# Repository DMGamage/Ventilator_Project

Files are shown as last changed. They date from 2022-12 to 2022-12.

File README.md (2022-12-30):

# Ventilator_Project

## The Repository
This repository is where Me and Chamika have developed a Opensource Ventilator Project in Corona Pandamic Situation as a group project on April of 2020. The main purpose of this project is to develop Portable Ventilator that can assist the patient lung pressure . And further more I use this project to develop my ability to work with the arduino and Solidworks and Matlab Designing Skills. I have published our full source code Design files in this repository. 

Ventilator_Project (https://www.youtube.com/watch?v=OVwWnZSBNhI)

### Solidworks Assemble Design1
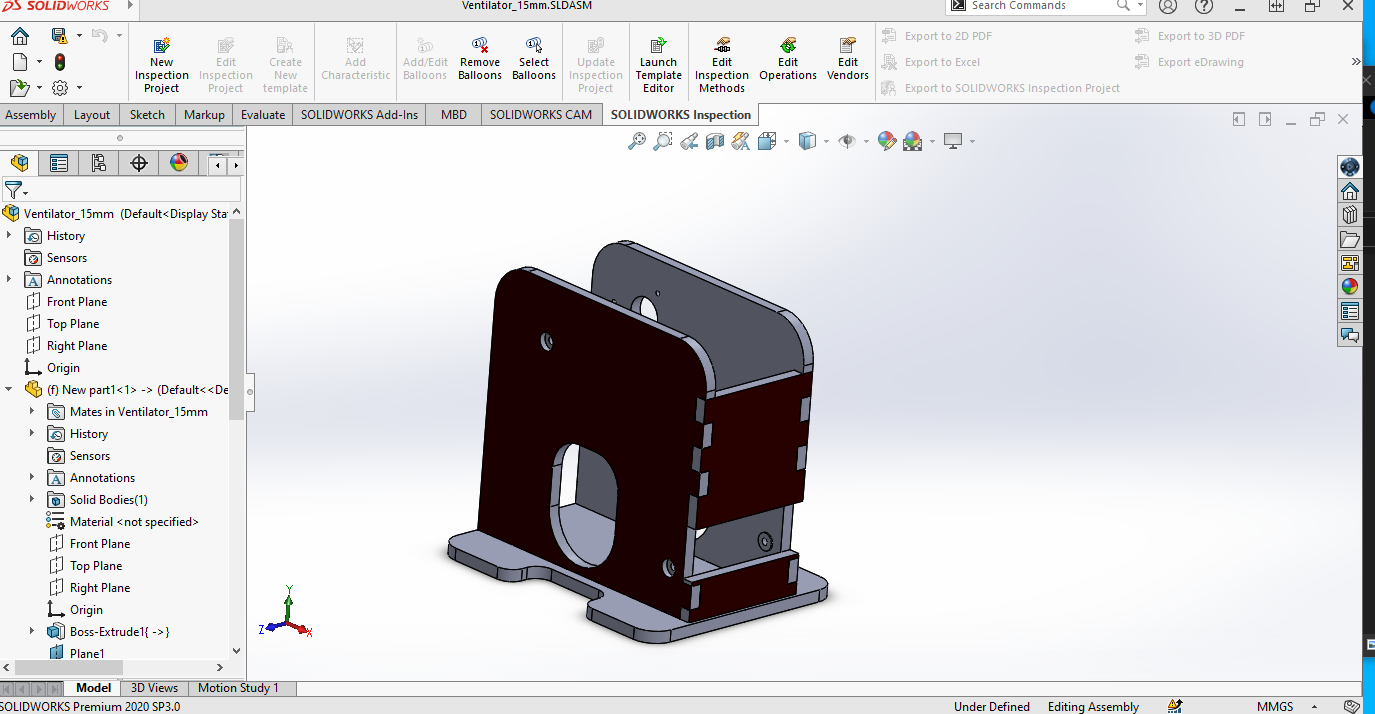
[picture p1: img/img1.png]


### Cam Mechanism Designing Using Matlab
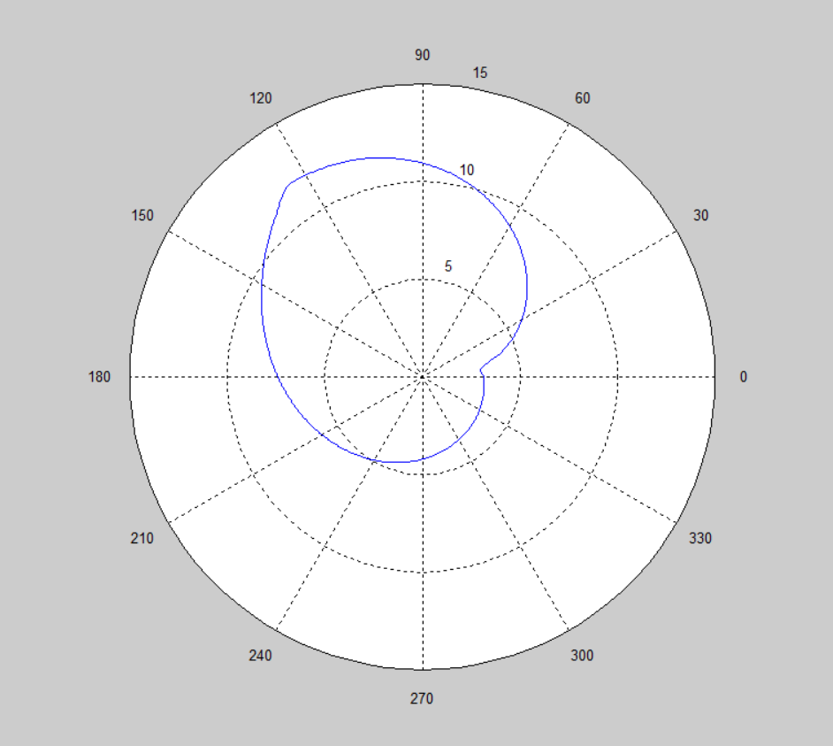
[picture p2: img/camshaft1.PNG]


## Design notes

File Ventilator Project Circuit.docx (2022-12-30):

Ventilator Project Circuit

Parts list

- LCD I2C 16x2 inbuilt display brightness adjustment
- Arduino Nano / Uno
- 30A monster shield board
- 3 push on/off buttons (JST Connectors for setting pushbutton in the casing)
- Encoder input Respiratory rate (Hall sensor to Interrupt or Phase AB encoder)
- Airspeed sensor or BMP 180 sensor
- Piezo buzzer

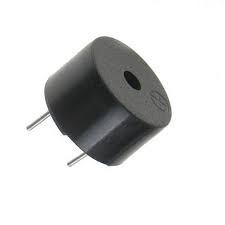
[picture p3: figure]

Basic Machine Connections

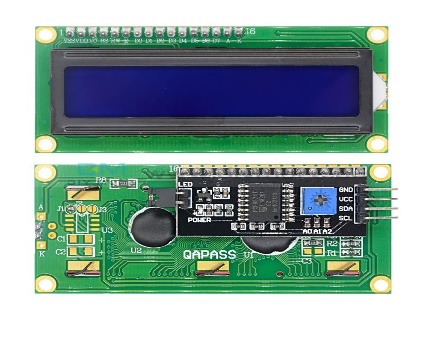
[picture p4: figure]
Using a 16x2 I2C LCD display with ESP32 - Electronics-Lab

Connections

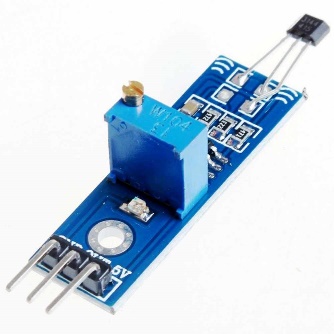
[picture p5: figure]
LM393 3144 Hall Sensor Module

Buzzer

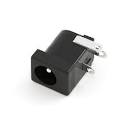
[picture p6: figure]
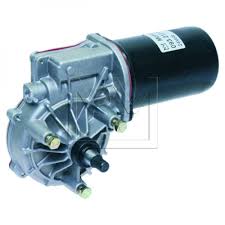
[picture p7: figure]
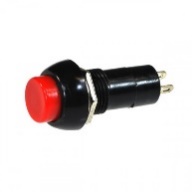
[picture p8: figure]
Push Button On Off Switch
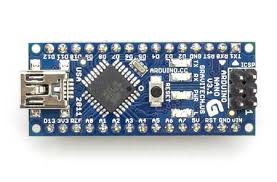
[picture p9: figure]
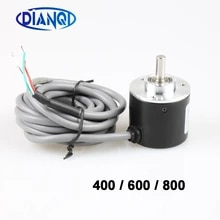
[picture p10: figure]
400 600 360 Pulses Incremental Optical Rotary Encoder AB Two-phase 5-26V 400 Pulses Incremental Optical Rotary Encoder

Power Supply 5V

JST 4 pin Connector to PCB

Respiratory rate increment

Respiratory rate decrement

Dual Motor Shield for redundant Motor control

I2C LCD

Interrupt pin 2,3

JST connector for easily connect either system

Start

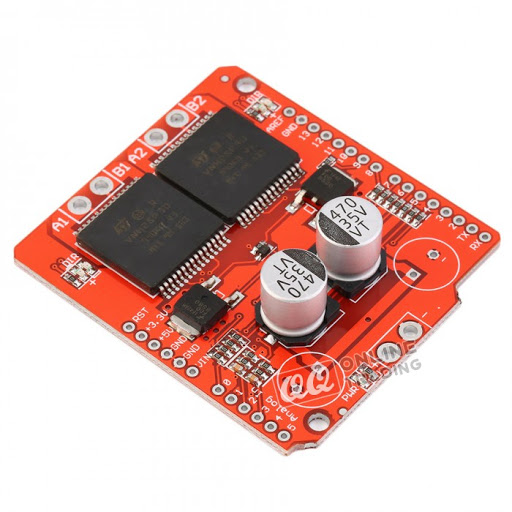
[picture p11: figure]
Monster Moto Dual-Channel Motor Driver VNH2SP30 High-current up to ...

12V supply

Improvements

Airspeed Flow and Pressure measurement or BMP 180 based pressure measurements

- MPXV7002DP Differential Pressure on Analog A5/A4
- BMP 180 I2C Pressure sensor and temperature sensor I2c Connection

Note: Please Keep other extra pins connected to an JST 2.54 connector or pads where as we can use them for any other requirement situation easily without tracing wires over the cct which could arise on Covid epidemic situation.

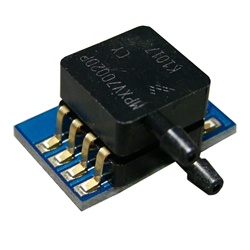
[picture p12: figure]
Using an Airspeed Sensor — Plane documentation

Analog Connection to A4 or A5

JST connector

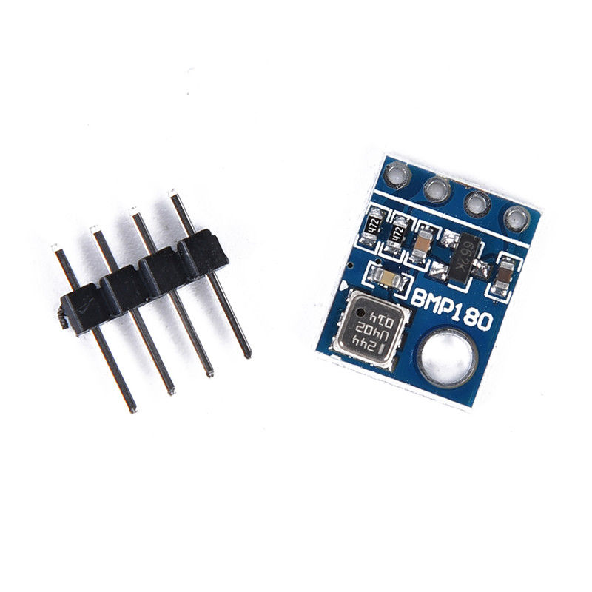
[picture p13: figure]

I2C connection

JST connector 4 pin (2.54)

- Humidity control and O2 concentrations system will be developed separately whereas

parts have to import, which is not locally available at this moment.

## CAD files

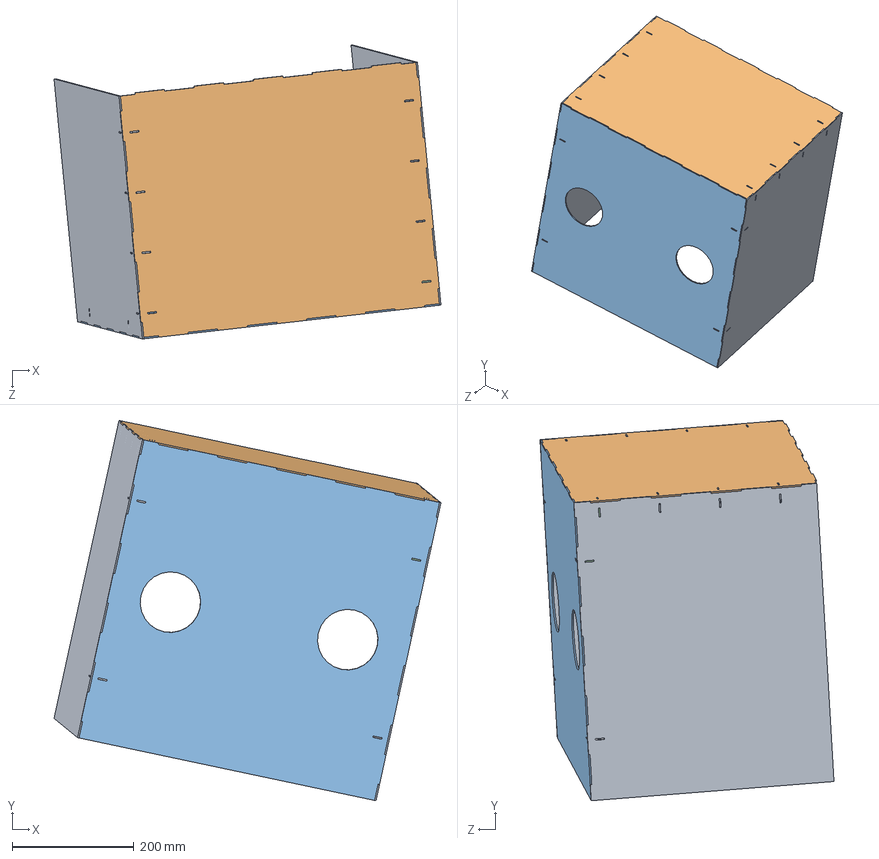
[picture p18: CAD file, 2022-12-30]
Covid_Safebox/Safebox.SLDASM
636.6 x 625.9 x 483.7 mm
Side 50X40 x 2
Top 50X40
Side Inlet plane
Corner x 2

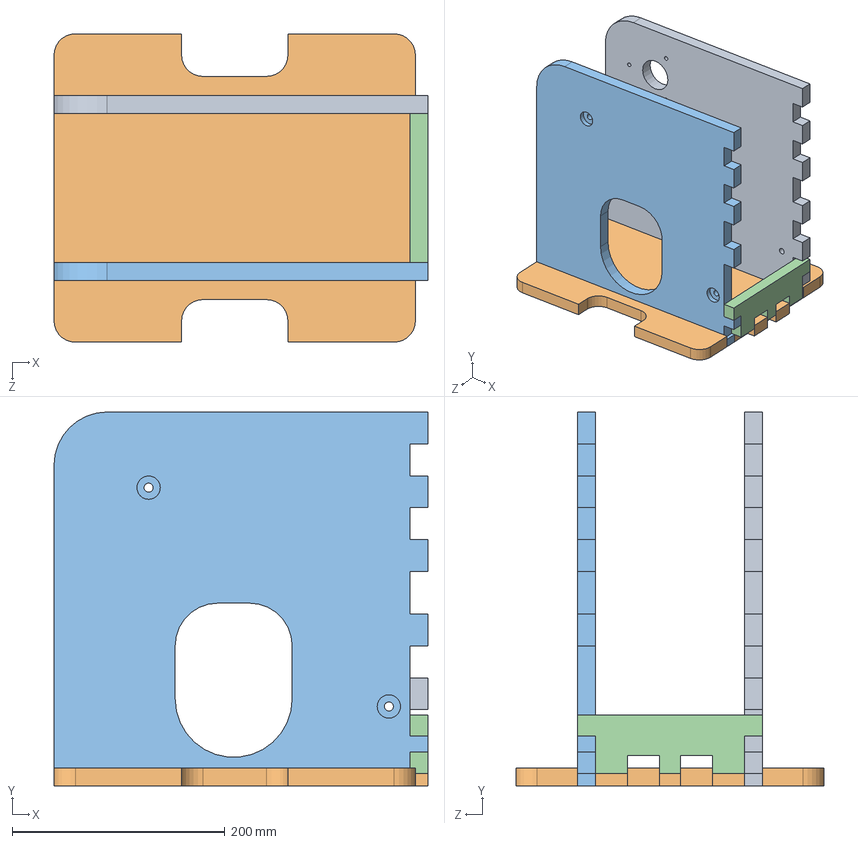
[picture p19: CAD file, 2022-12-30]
Solidworks Files/Assem1.SLDASM
351.8 x 351.8 x 290.0 mm
New part1
New part3
New part2
New part4

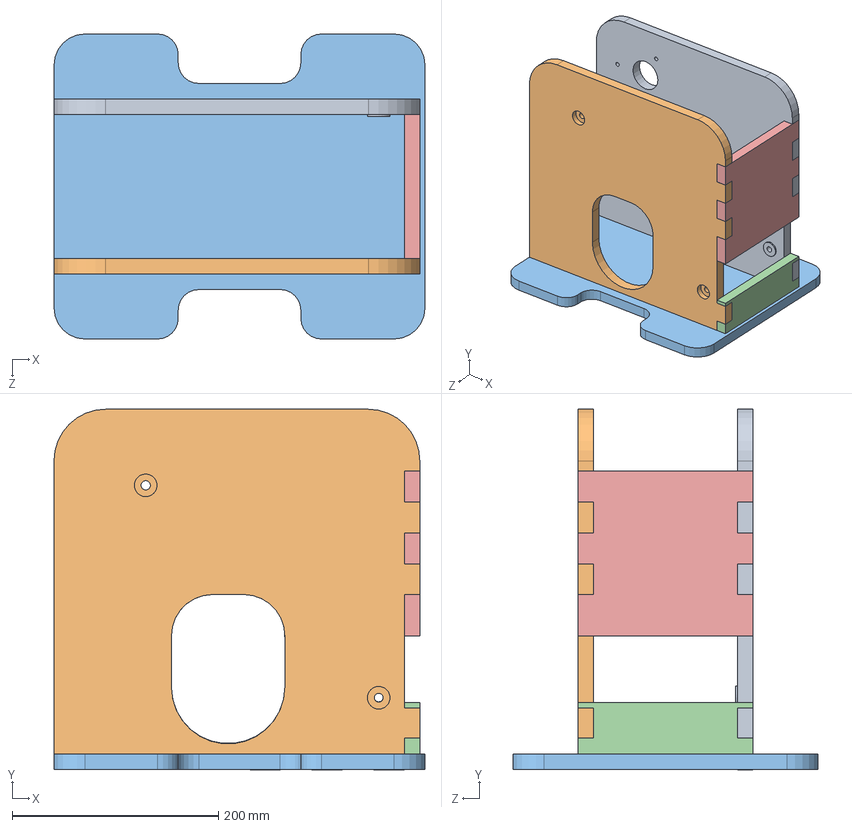
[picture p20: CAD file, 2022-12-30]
Solidworks Files/Ventilator_15mm.SLDASM
360.0 x 349.9 x 296.0 mm
New part1
New part2
front_bottom mount
Front_Top

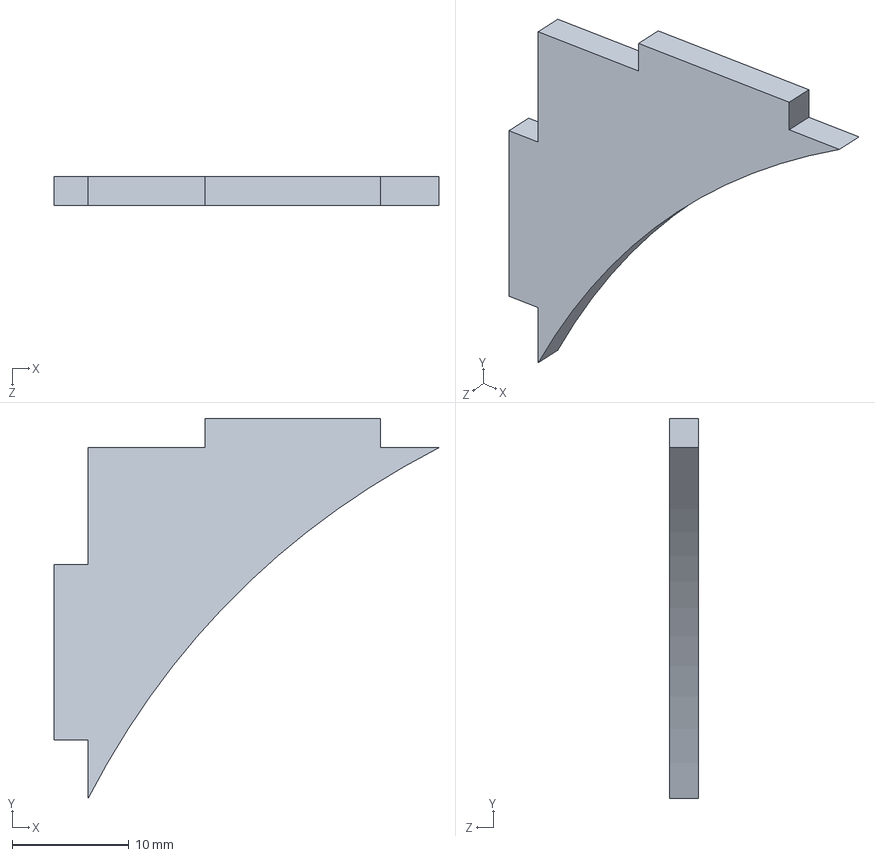
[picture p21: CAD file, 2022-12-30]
Covid_Safebox/Corner.SLDPRT
32.9 x 32.5 x 2.50 mm

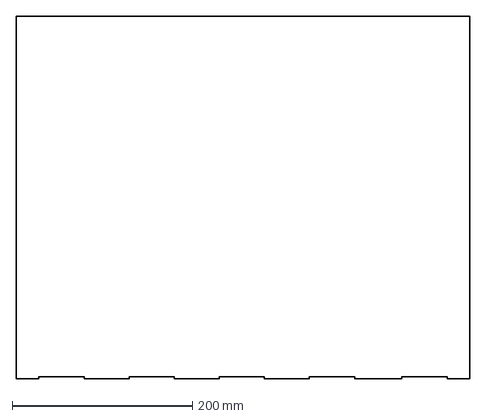
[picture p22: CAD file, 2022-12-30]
Covid_Safebox/lasercut files/Side 50X40.DXF
502.5 x 402.5 mm

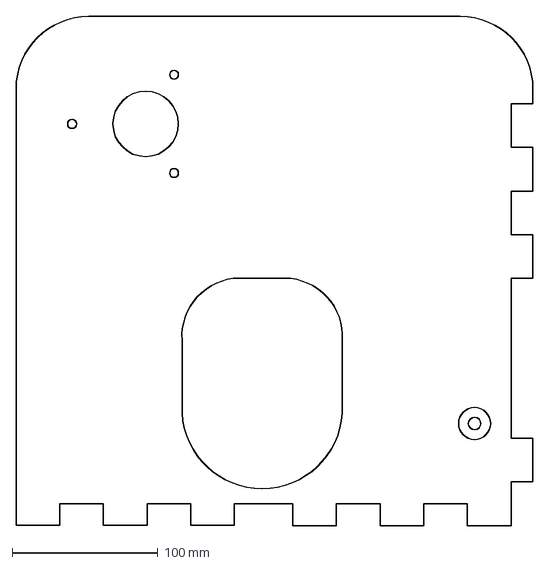
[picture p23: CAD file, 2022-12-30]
Solidworks Files/dxf/part3.DXF
355.0 x 349.9 mm

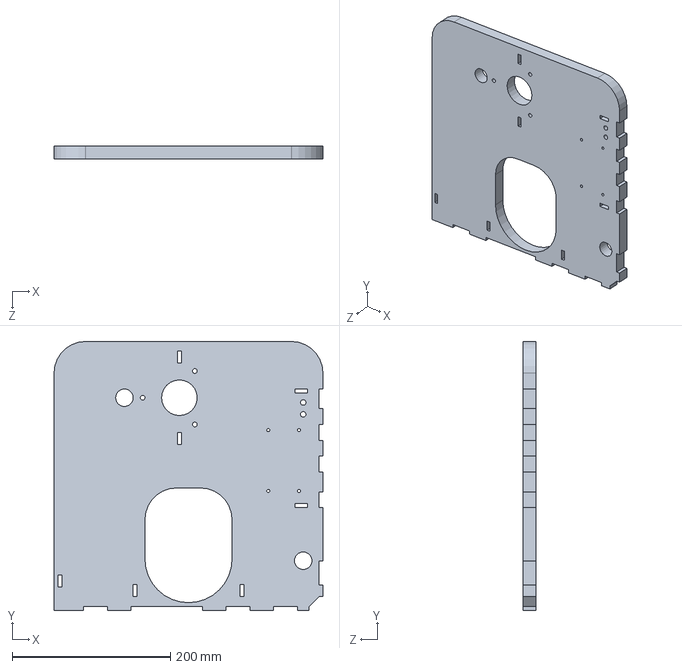
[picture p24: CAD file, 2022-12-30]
Solidworks Files/part1.SLDPRT
340.0 x 340.1 x 17.0 mm

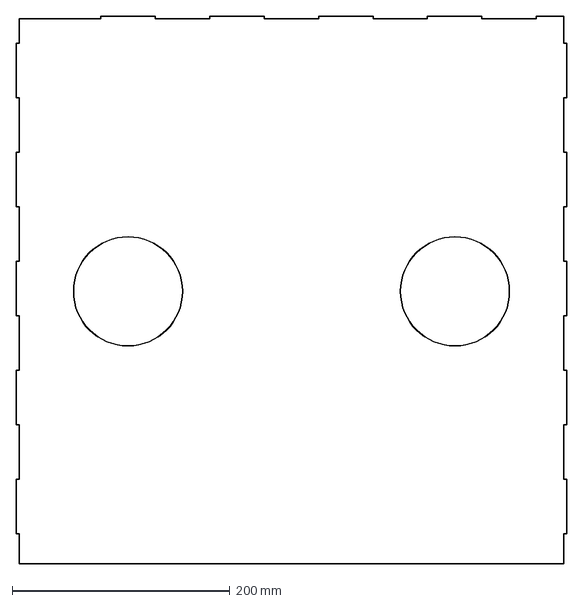
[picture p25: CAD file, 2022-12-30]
Covid_Safebox/lasercut files/Side Inlet plane.DXF
505.0 x 502.5 mm

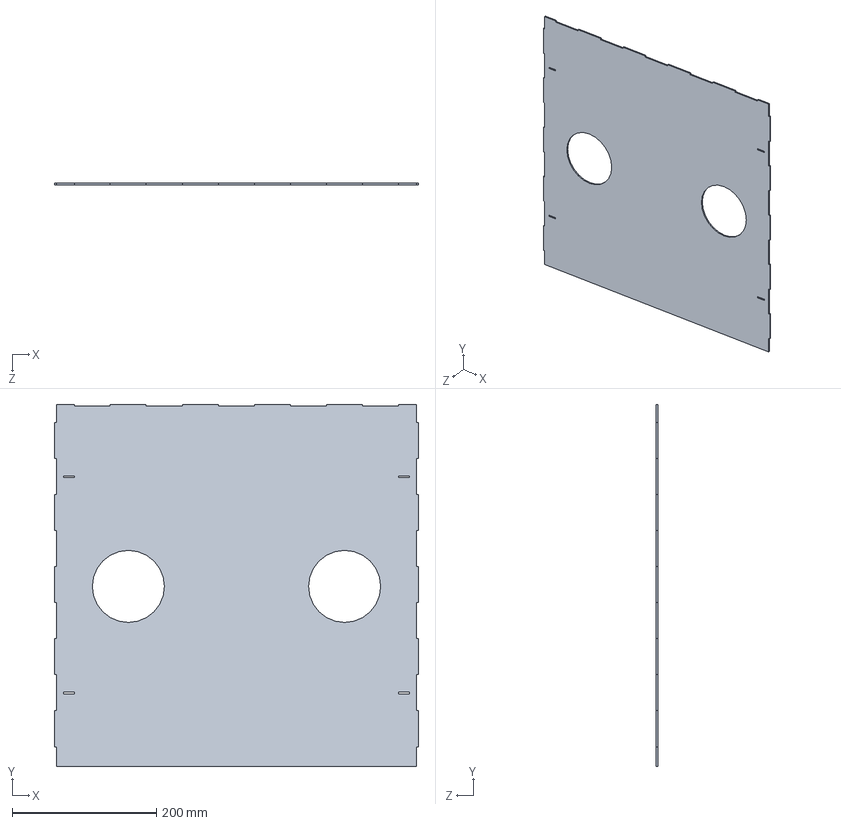
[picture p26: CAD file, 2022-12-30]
Covid_Safebox/Side Inlet plane.SLDPRT
505.0 x 502.5 x 2.50 mm

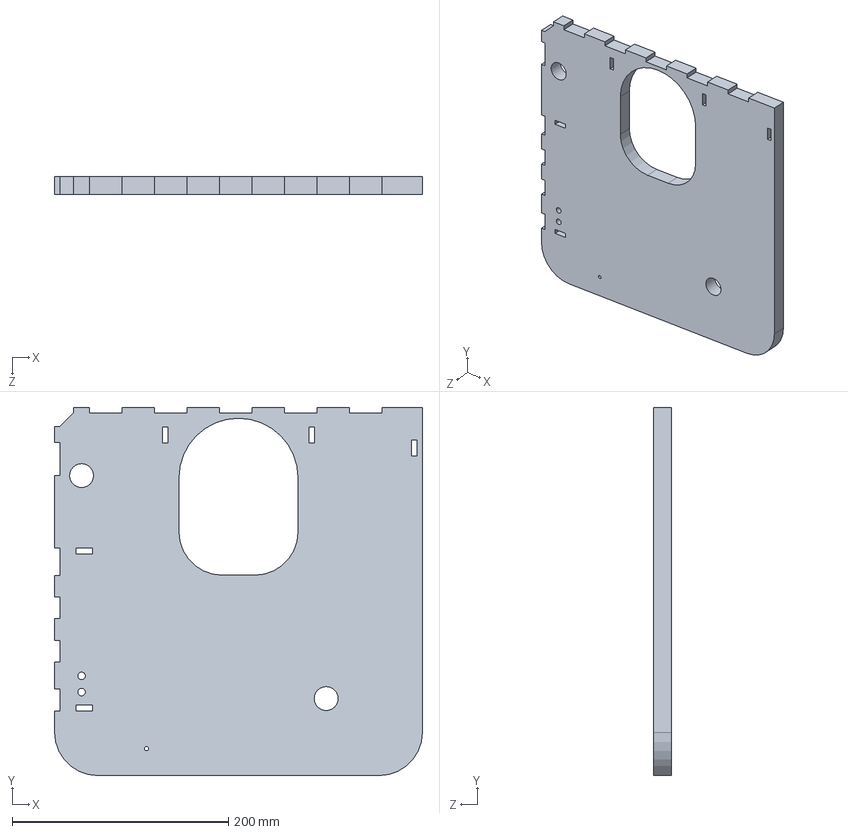
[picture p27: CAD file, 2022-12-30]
Solidworks Files/Part2.SLDPRT
340.0 x 340.2 x 17.0 mm

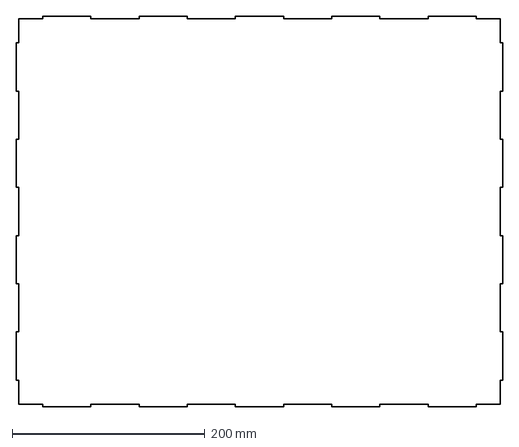
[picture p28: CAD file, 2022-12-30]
Covid_Safebox/lasercut files/Top 50X40.DXF
505.0 x 405.0 mm

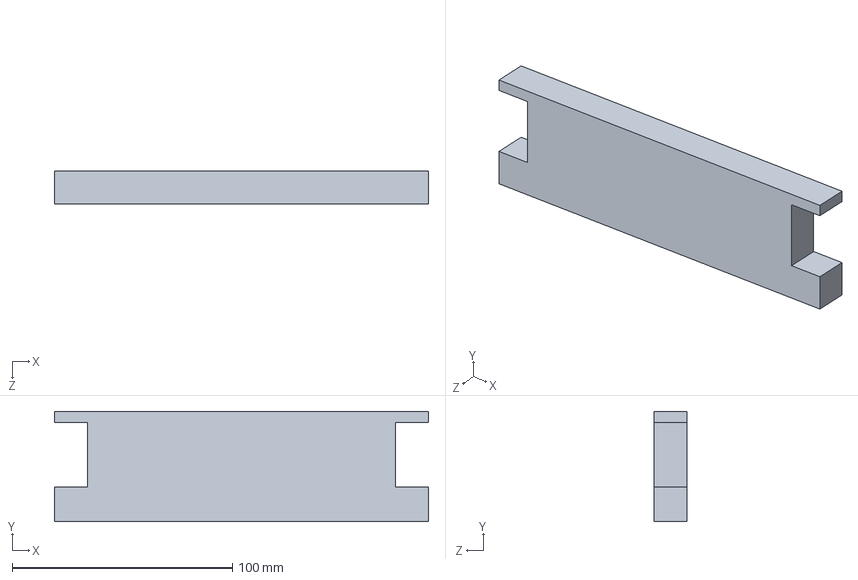
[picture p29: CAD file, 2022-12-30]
Solidworks Files/front_bottom mount.SLDPRT
170.0 x 50.0 x 15.0 mm

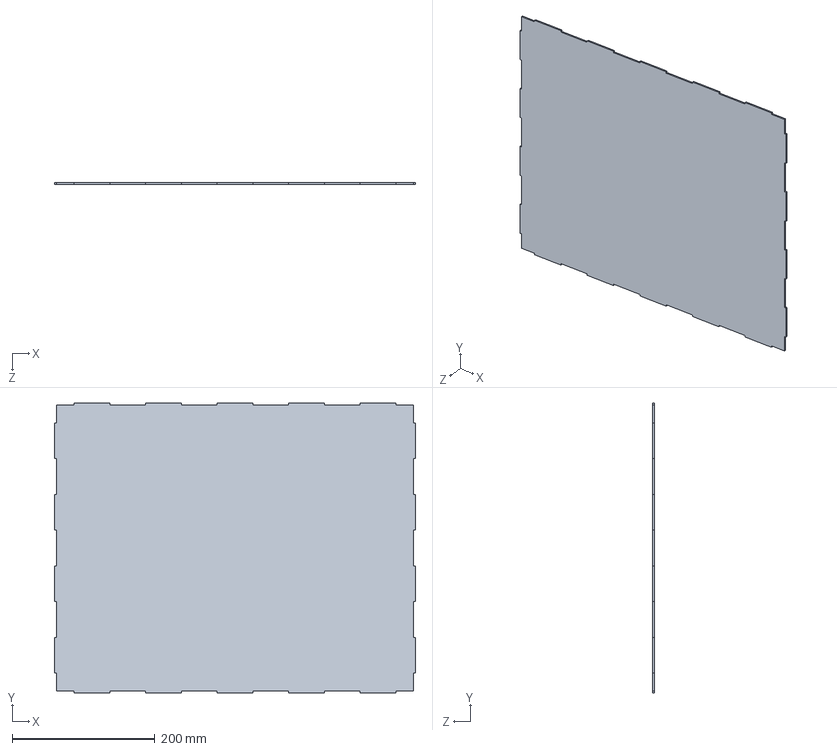
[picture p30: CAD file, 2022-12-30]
Covid_Safebox/Top 50X40.SLDPRT
505.0 x 405.0 x 2.50 mm

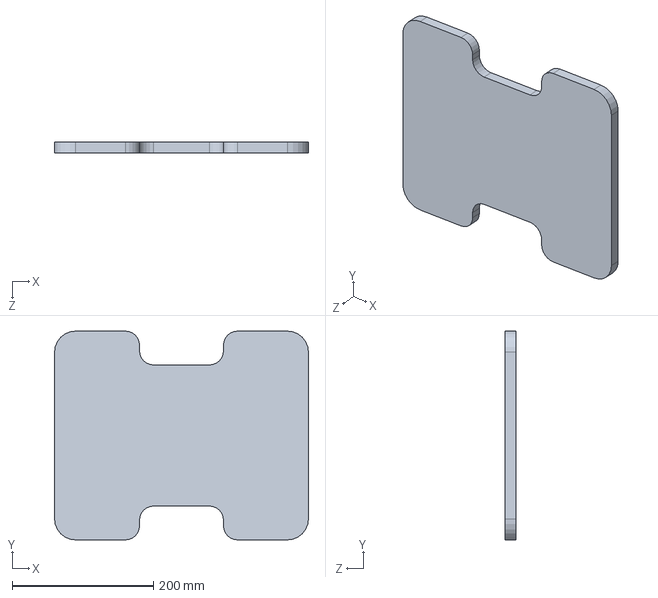
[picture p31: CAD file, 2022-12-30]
Solidworks Files/Part7.sldprt
360.0 x 296.0 x 15.0 mm

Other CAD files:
Solidworks Files/part new.SLDPRT
Covid_Safebox/Side 50X40.SLDPRT
Solidworks Files/New part2.SLDPRT
Solidworks Files/New part4.SLDPRT
Solidworks Files/Front_Top.SLDPRT
Solidworks Files/New part1.SLDPRT
Solidworks Files/New part3.SLDPRT
Solidworks Files/Part41.SLDPRT
Solidworks Files/Thread.SLDPRT
Solidworks Files/dxf/Front_Top.DXF
Solidworks Files/dxf/New part2.DXF
Solidworks Files/dxf/Part2.DXF
Solidworks Files/dxf/front_bottom mount.DXF
Solidworks Files/part new.DXF

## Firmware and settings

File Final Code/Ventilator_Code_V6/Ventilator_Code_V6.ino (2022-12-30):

#include <Wire.h>
#include <LiquidCrystal_I2C.h>
#include <sSense-BMx280I2C.h>
#include <Wire.h>

#define MCP4725_ADDR 0x60

#define V_BPM  12
#define KC_BPM 2800
// Pin diclareration

#define INC 4  // increase button
#define DECR 10  // decrease button
#define START 11 // Start 
#define SET_RESET 12  // Set Reset 
#define BPMpin 2
#define Buzzer 13

// Loop time declarations
#define FAST_LOOP 20 // 50 ms loop
#define SLOW_LOOP 200
#define RESP_LOOP 3000
#define SERIAL_SPEED  9600
// Variable declaration
int BPM = 0;
int PEEP = 5;
int PIP = 30;

float pressure_pre = 1027;
int voltage = 0;
int SetBPM = 45;
int SetPEEP = 5;
int SetPIP = 30;
boolean Set = true;
int STARTED = false;
int input_loc = 0; // define the location of curser  BPM , PEEP or PIP
int Inputs[] = {SetBPM, PEEP, PIP};
unsigned long Time1 = 0;
unsigned long Time2 = 0;
unsigned long Time3 = 0;
int counter = 0;
// BPM counter
int BPM_Counter = 0;
float T_BPM = 0;
float t1_bpm = 0;
int T_buzzer = 0;
boolean Mute = false;
boolean SetAlarm = false;
boolean PEEP_SET = false;
float temp(NAN), hum(NAN), pres(NAN);
int   Pressure[120];
float tempint(NAN), humint(NAN), presint(NAN);
int IndexP = 0;
int MaxP = 0;
int MinP = 0;
boolean BME_Presence = true;

BMx280I2C::Settings settings(
  BME280::OSR_X2,
  BME280::OSR_X1,
  BME280::OSR_X16,
  BME280::Mode_Normal,
  BME280:: StandbyTime_500us,
  BME280::Filter_16,
  BME280::SpiEnable_False,
  0x76 // I2C address. I2C specific.
);

BMx280I2C ssenseBMx280(settings);
LiquidCrystal_I2C lcd(0x27, 16, 2);
void setup()
{

  pinMode(INC, INPUT);
  pinMode(DECR, INPUT);
  pinMode(START, INPUT);
  pinMode(SET_RESET, INPUT);
  pinMode( Buzzer, OUTPUT);
  Serial.begin(9600);
  // LCD intializing
  lcd.init();
  lcd.backlight();
  lcd.setCursor(3, 0);
  lcd.print("Ventilator");
  delay(2000);
  lcd.clear();
  lcd.setCursor(1, 0);
  lcd.print("Set SPEED:");
  lcd.print(SetBPM);
  lcd.setCursor(0, 1);
  lcd.print("PEEP>");
  lcd.print(PEEP);
  lcd.print("  PIP<");
  lcd.print(PIP);
  delay(1000);

  Wire.beginTransmission(MCP4725_ADDR);
  Wire.write(64);

  voltage = 0;
  // cmd to update the DAC
  Wire.write(voltage >> 4);       // the 8 most significant bits...
  Wire.write((voltage & 15) << 4); // the 4 least significant bits...
  Wire.endTransmission();
  Wire.begin();

  // pressure sensor
  for (int i = 0; i < 120; i++) // pressur array to hold all pressure values
    Pressure[i] = 0;


  Wire.begin();
  while (!ssenseBMx280.begin() && BME_Presence)
  {
    DebugPort.println("Could not find BME/BMP280 sensor!");
    delay(500);
    counter++;
    lcd.setCursor(0, 1);
    lcd.print("Intialize Sensors");
    if (counter > 20)
      BME_Presence = false;
  }

  if (BME_Presence)
  {
    switch (ssenseBMx280.chipModel())
    {
      case BME280::ChipModel_BME280:
        DebugPort.println("Found BME280 sensor! Humidity available.");
        break;
      case BME280::ChipModel_BMP280:
        DebugPort.println("Found BMP280 sensor! No Humidity available.");
        break;
      default:
        DebugPort.println("Found UNKNOWN sensor! Error!");
    }

    // Change some settings before using.
    settings.tempOSR = BME280::OSR_X4;

    ssenseBMx280.setSettings(settings);


    BME280::TempUnit tempUnit(BME280::TempUnit_Celsius);
    BME280::PresUnit presUnit(BME280::PresUnit_Pa);

    ssenseBMx280.read(presint, tempint, humint, tempUnit, presUnit);
    delay(1000);
    ssenseBMx280.read(presint, tempint, humint, tempUnit, presUnit);
    delay(1000);
    ssenseBMx280.read(presint, tempint, humint, tempUnit, presUnit);
    delay(1000);
  }
  else
  {
    lcd.setCursor(0, 1);
    lcd.print("BME Sensor ERR");
  }
  //  time loop init
  Time1 = millis();
  Time2 = millis();
  Time3 = millis();
  //  time loop init
  TCCR1A = 0;
  TCCR1B = 0;
  TCNT1  = 0;

  noInterrupts();           // disable all interrupts
  OCR1A = 625;           // compare match register 16MHz/256/2Hz 10ms time 62500/100
  TCCR1B |= (1 << WGM12);   // CTC mode
  TCCR1B |= (1 << CS12);    // 256 prescaler
  TIMSK1 |= (1 << OCIE1A);  // enable timer compare interrupt
  interrupts();             // enable all interrupts
  // BPM
  attachInterrupt(digitalPinToInterrupt(BPMpin), BPM_Loop, FALLING);


}

void loop()
{

  Check_Input();
  Check_Sensors();
  Motor_update();


}

void Check_Input()
{
  int button_press = false;
  if (digitalRead(SET_RESET))
  {
    digitalWrite(Buzzer, HIGH);
    while (digitalRead(SET_RESET)) continue;
    digitalWrite(Buzzer, LOW);
    Set = ~Set;
    if(SetAlarm) Mute = true;
    button_press = true;

    input_loc++;  if (input_loc > 2)   input_loc = 0;
  }
  else if (digitalRead(INC))
  {
    digitalWrite(Buzzer, HIGH);
    while (digitalRead(INC)) continue;
    digitalWrite(Buzzer, LOW);
    button_press = true;
    if (!Set)
    { if (STARTED)  input_loc = 0;
      input_loc++;  if (input_loc > 2)   input_loc = 0;

    }
    else
    { if (STARTED)  input_loc = 0;
      Inputs[input_loc] = Inputs[input_loc] + 1;
    }
  }
  else if (digitalRead(DECR))
  {
    digitalWrite(Buzzer, HIGH);
    while (digitalRead(DECR)) continue;
    button_press = true;
    digitalWrite(Buzzer, LOW);
    if (!Set)
    {
      input_loc--;  if (input_loc < 0)   input_loc = 2;
      
      
      if (STARTED)  input_loc = 0;
    }
    else
    {
      if (STARTED)  input_loc = 0;
      Inputs[input_loc] = Inputs[input_loc] - 1;
    }
  }
  else if (digitalRead(START))
  {
    digitalWrite(Buzzer, HIGH);
    while (digitalRead(START)) continue;
    button_press = true;
    digitalWrite(Buzzer, LOW);
    STARTED = ~STARTED ;
    Mute = false;
    input_loc = 0;
  }
  if (button_press)
  {
    Display();
    button_press = false;
  }
}

void Display()
{

  if (Inputs[0] < 0) Inputs[0] = 0;
  if (Inputs[0] > 100) Inputs[0] = 100;
  if (Inputs[1] < 0)   Inputs[1] = 0;
  if (Inputs[1] > 25) Inputs[1] = 25;
  if (Inputs[2] < 10) Inputs[2] = 10;
  if (Inputs[2] > 50) Inputs[2] = 50;
  SetBPM = Inputs[0];
  SetPEEP = Inputs[1];
  SetPIP = Inputs[2];
  lcd.clear();
  lcd.setCursor(1, 0);
  lcd.print("Set SPEED:");
  lcd.print(SetBPM);
  lcd.setCursor(0, 1);
  lcd.print("PEEP>");
  lcd.print(SetPEEP);
  lcd.print("  PIP<");
  lcd.print(SetPIP);


}


void Check_Sensors()
{
  if (Time1 < 0) Time1 = 0;
  if (Time2 < 0) Time2 = 0;
  if (Time3 < 0) Time3 = 0;

  if ((millis() - Time2) > FAST_LOOP)
  {
    Time2 = millis();
    if (BME_Presence)
    {
      BME280::TempUnit tempUnit(BME280::TempUnit_Celsius);
      BME280::PresUnit presUnit(BME280::PresUnit_Pa);
      ssenseBMx280.read(pres, temp, hum, tempUnit, presUnit);
      Pressure[IndexP] = int((pres - presint) * 0.010197162129779282);
      // Pressure Array
      IndexP = IndexP + 1;

      if (IndexP > 119)
      {
        IndexP = 0; // reset on overflow
      }

      Serial.print(Pressure[IndexP]);
      Serial.println(",");
    }
    else
      Serial.println("BME SENSOR ERROR");
  }


  if ((millis() - Time1) > SLOW_LOOP)
  {
    Time1 = millis();
    if (STARTED)
    {

      //client->print("Pressure: ");
      lcd.clear();
      lcd.setCursor(0, 0);
      if (PEEP_SET)
      {
        lcd.print("SPD|BPM|PIP|RH");
      }
      else
        lcd.print("SPD|BPM|PIP|PEP");
      lcd.setCursor(0, 1);
      BPM = 60 / T_BPM;
      lcd.print(SetBPM);
      lcd.setCursor(3, 1); lcd.print("|");
      lcd.print(BPM);

      lcd.setCursor(7, 1); lcd.print("|");

      if (BME_Presence)
      {

        lcd.print(PIP);
        lcd.setCursor(11, 1); lcd.print("|");

        if (PEEP_SET)

        {
          lcd.print(hum, 0);
        }
        else
          lcd.print(PEEP);
        delay(10);
      }
      else
      {
        lcd.print("NA");
        lcd.setCursor(11, 1); lcd.print("|"); lcd.print("NA");
        delay(10);
      }
    }

  }


  if ((millis() - Time3) > RESP_LOOP) // 6s loop
  {
    Time3 = millis();

    MaxP = Pressure[0];
    MinP = Pressure[0];
    for (int i = 0; i < 120; i++)
    {
      //  Serial.println(Pressure[i]);


      if ((Pressure[i] > MaxP)) MaxP = Pressure[i];
      if ((Pressure[i] < MinP) && Pressure[i] != 0 ) MinP = Pressure[i];

    }

    PIP = MaxP;
    PEEP = MinP;

    if (STARTED&&BME_Presence && Set && BPM > 10 && PIP > SetPIP && !Mute)
    {
      SetAlarm = true;
      lcd.setCursor(7, 1); lcd.print("|"); lcd.print("ERR");
      digitalWrite(Buzzer, HIGH);
      delay(50);
      digitalWrite(Buzzer, LOW);
      delay(50);
      digitalWrite(Buzzer, HIGH);
      delay(50);
      digitalWrite(Buzzer, LOW);
      delay(500);
    }
    if (STARTED&&BME_Presence && BPM > 10 && Set && PEEP < SetPEEP && !Mute && PIP > SetPEEP   ) //
    {
      SetAlarm = true;
      lcd.setCursor(11, 1); lcd.print("|"); lcd.print("ERR");
      digitalWrite(Buzzer, HIGH);
      delay(200);
      digitalWrite(Buzzer, LOW);
      delay(200);
      digitalWrite(Buzzer, HIGH);
      delay(200);
      digitalWrite(Buzzer, LOW);
      delay(500);
    }

    if (PEEP_SET) PEEP_SET = false;
    else
      PEEP_SET = true;
    Serial.print("PEEP_SET");
    Serial.println(PEEP_SET);

  }
}

void Motor_update()
{
  if (STARTED)
  {
    voltage = SetBPM * V_BPM + KC_BPM;
    voltage = min(voltage, 4095);

  }
  else
    voltage = 0;
  Wire.beginTransmission(MCP4725_ADDR);
  Wire.write(64);
  Wire.write(voltage >> 4);       // the 8 most significant bits...
  Wire.write((voltage & 15) << 4); // the 4 least significant bits...
  Wire.endTransmission();
  Wire.begin();
}

void BPM_Loop()
{
  float temp_BPM = BPM_Counter * 0.01;

  if (temp_BPM <= 10 and temp_BPM >= 0.45)
    T_BPM = temp_BPM;

  BPM_Counter = 0;
}

ISR(TIMER1_COMPA_vect)          // timer compare interrupt service routine

{


  BPM_Counter++;

  if (BPM_Counter >= 600)
  {
    T_BPM = 2000;
  }

}
